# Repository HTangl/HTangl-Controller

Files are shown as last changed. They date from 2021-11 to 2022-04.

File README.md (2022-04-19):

# HTangl-Controller

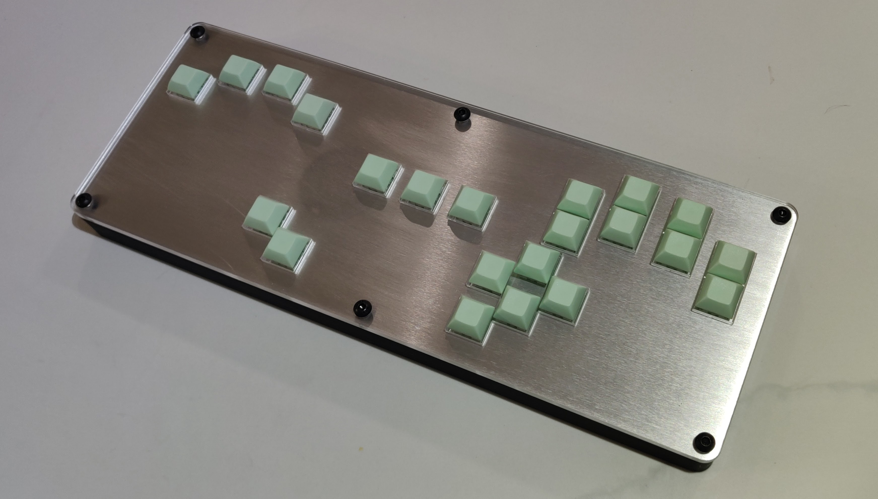
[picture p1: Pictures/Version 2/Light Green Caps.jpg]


The HTangl controller is an all digital game controller mainly made for Super Smash Brothers Melee  
but it can be used for many different games including traditional fighting games and platformers.  

It runs on a [modified version](https://github.com/HTangl/HTangl-Firmware) of the [HayB0XX firmware](https://github.com/JonnyHaystack/HayB0XX).  

The design of the controller is based on [The B0XX](https://b0xx.com/), [Frame 1](https://frame1.gg/) and [GCCMX](https://www.craneslab.xyz/projects/mx)  

This controller is not especially easy to DIY, Version 2 requiers a large 3D printed case which I print all in one piece on a large format FDM printer. The top panel and switch plate are also laser cut and the PCB requires some custom parts like the 2 USB ports. If you are not already somewhat familier with 3D printing, soldering, CAD and PCB manufacturing then I do not recommend trying to make one of these controllers.  

I created a simplified version of this controller specifically meant for DIY called the [BudgeTangl](https://github.com/HTangl/BudgeTangl), please check out that repository if you're just looking to make a simple controller.  

This controller is licensed under the CERN Open Hardware Licence Version 2 - Strongly Reciprocal. Please read the license in this repository and visit https://ohwr.org/cernohl for more information. This license allows you to make a modified or unmodified version of the controller for yourself or to sell provided you follow the guidelines of the license. The strongly reciprocal version of the license I have chosen requires that you use this same license if you decide to make modifications to any of the files in this repository.

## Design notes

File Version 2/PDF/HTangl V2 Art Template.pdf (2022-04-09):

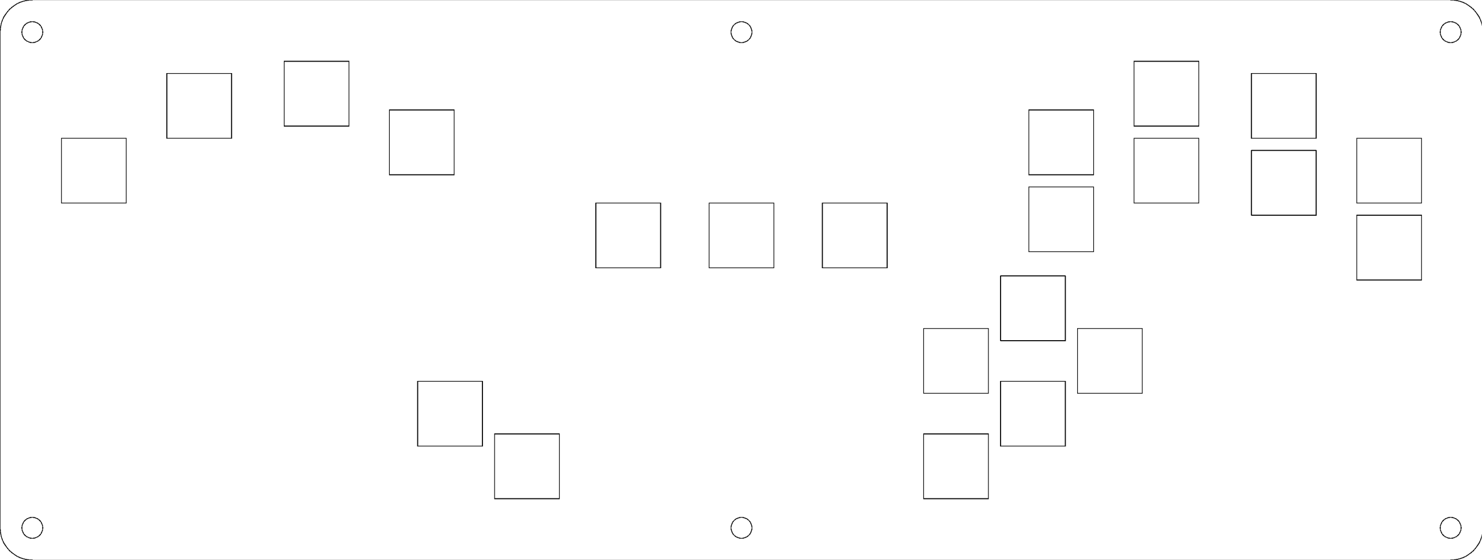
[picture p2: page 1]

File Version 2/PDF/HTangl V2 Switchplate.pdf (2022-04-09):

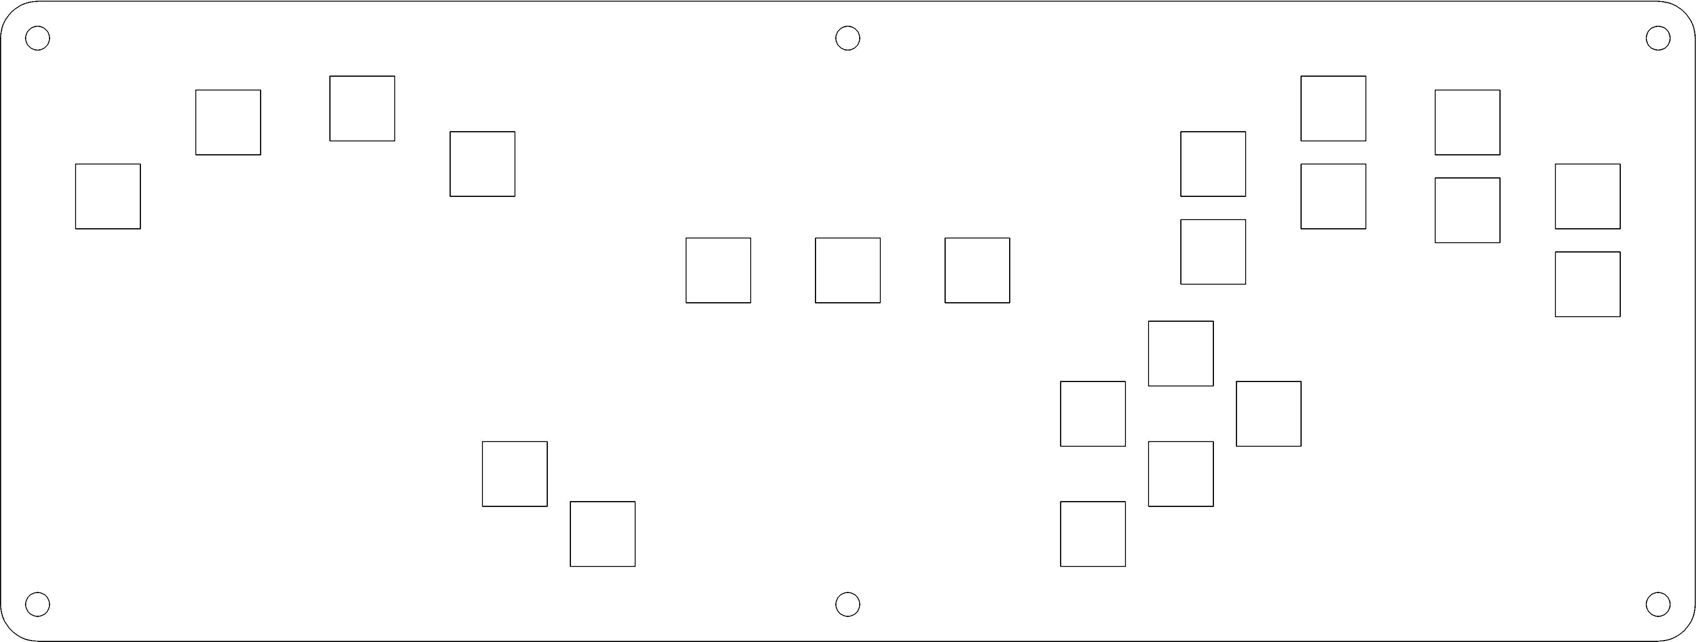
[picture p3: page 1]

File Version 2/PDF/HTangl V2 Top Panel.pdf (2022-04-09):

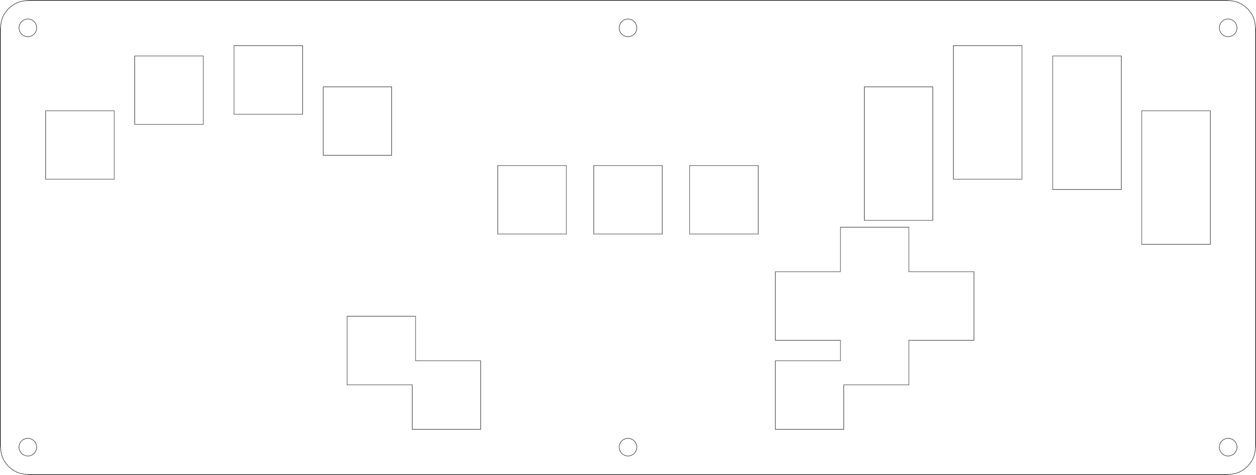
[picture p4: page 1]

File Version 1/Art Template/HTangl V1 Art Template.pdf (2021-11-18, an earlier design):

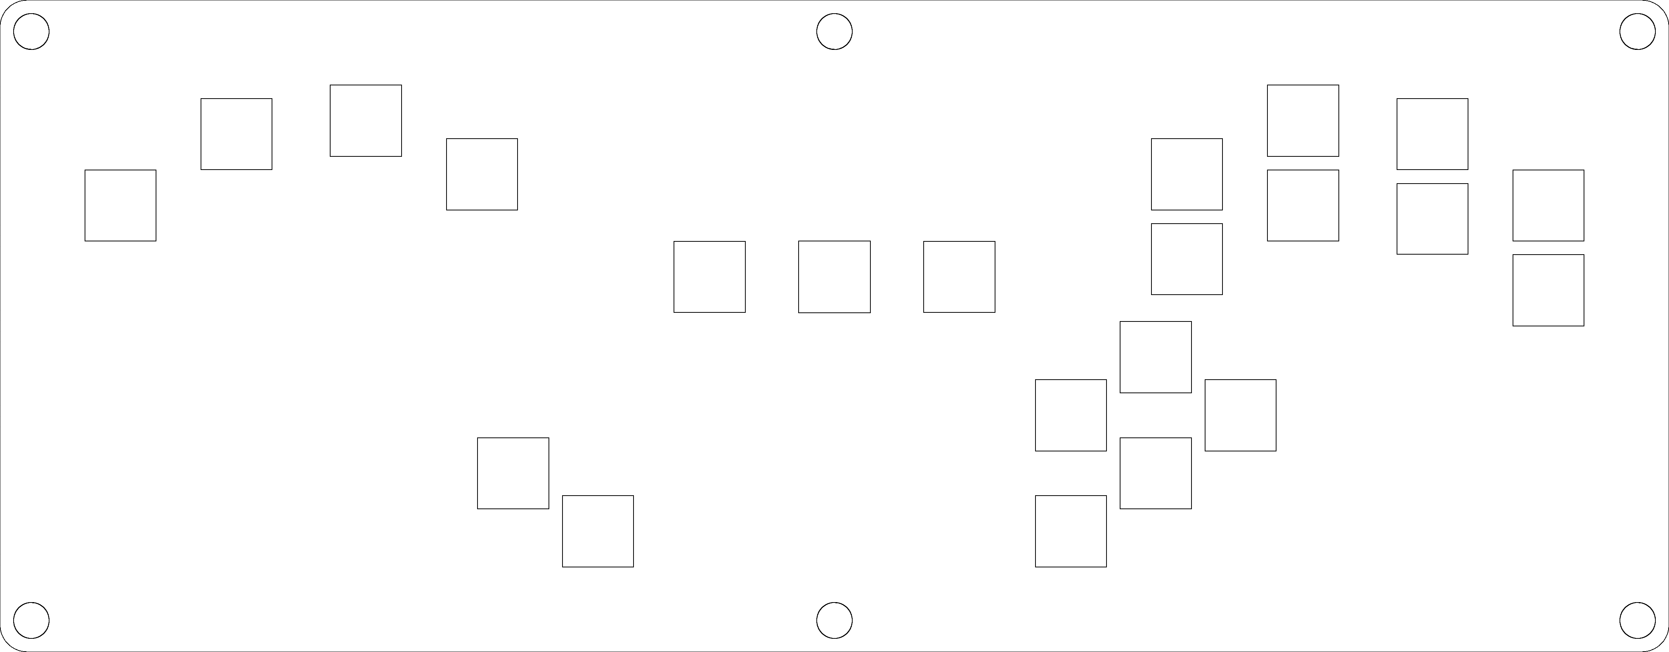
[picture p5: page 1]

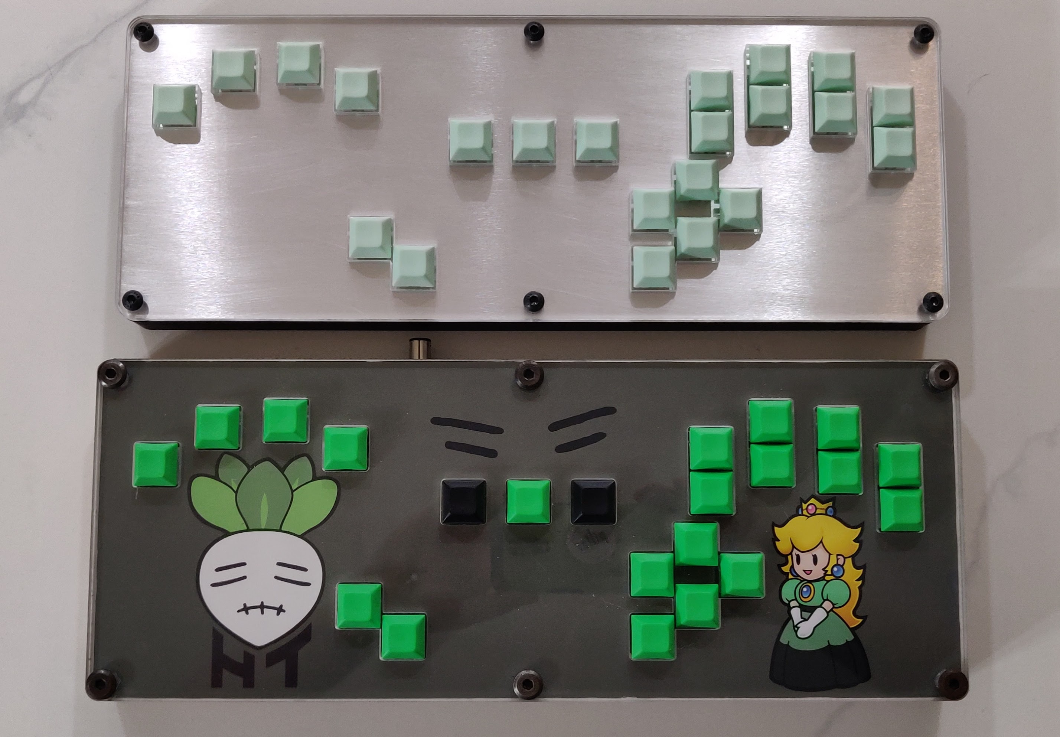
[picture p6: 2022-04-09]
Pictures/Version 2/V1 vs V2.jpg

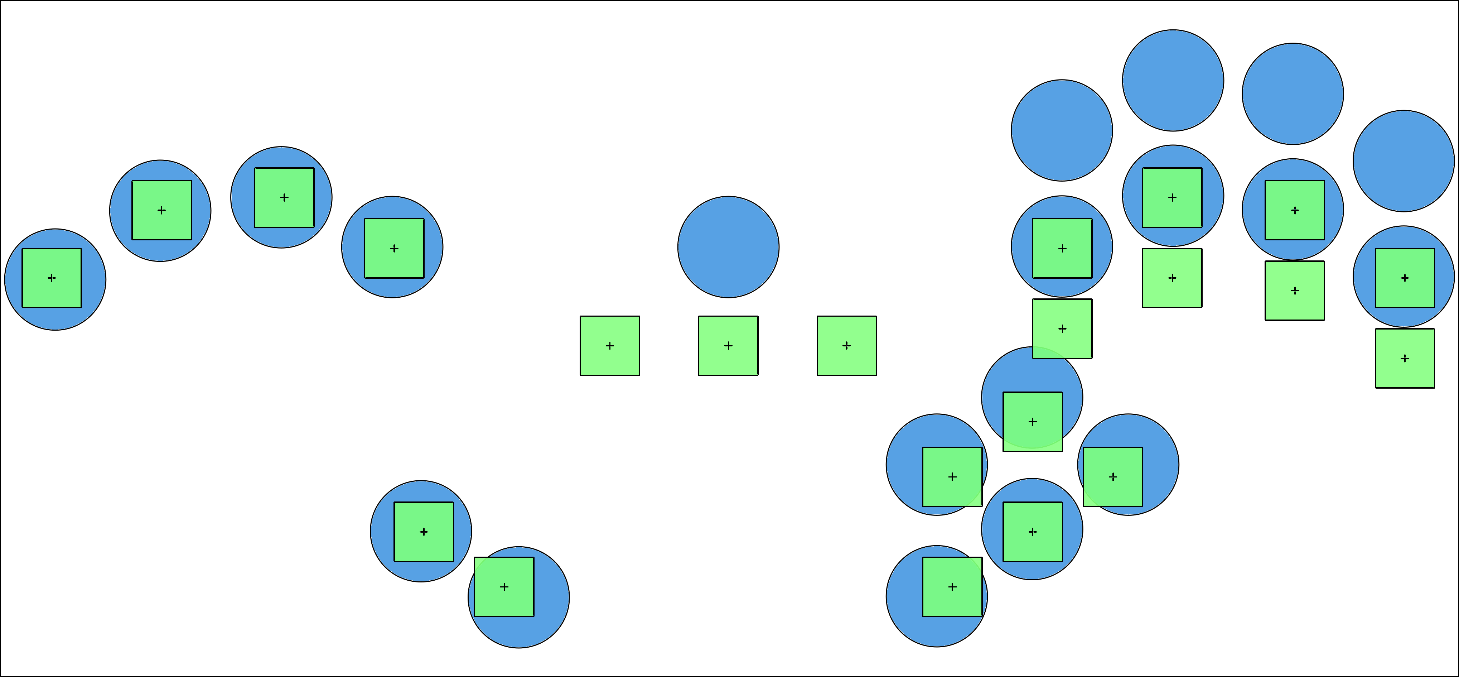
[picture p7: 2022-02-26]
Pictures/HTangl_B0XX_Comparison.png

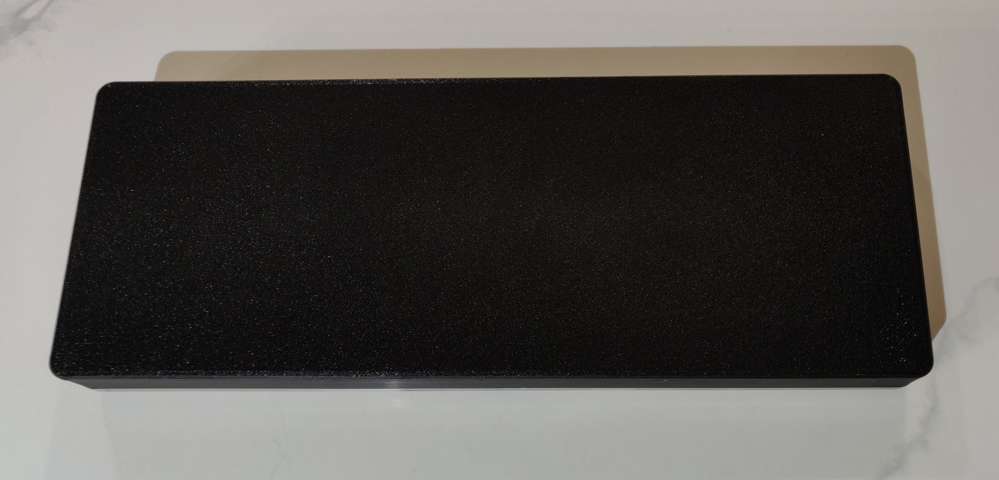
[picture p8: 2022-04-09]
Pictures/Version 2/Bottom.jpg

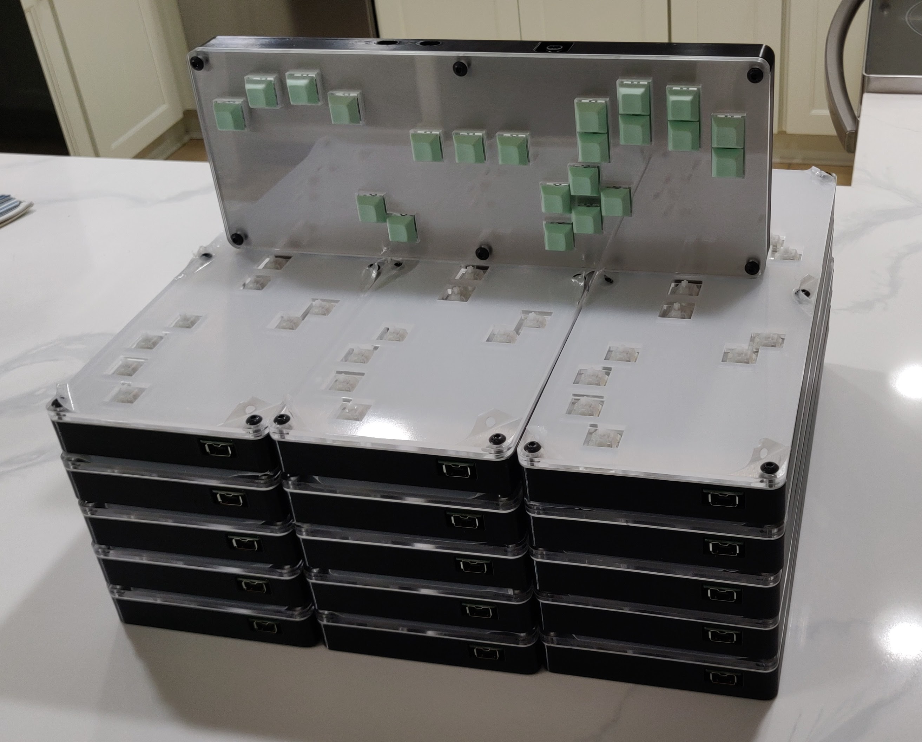
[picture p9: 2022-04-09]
Pictures/Version 2/Stack 1.jpg

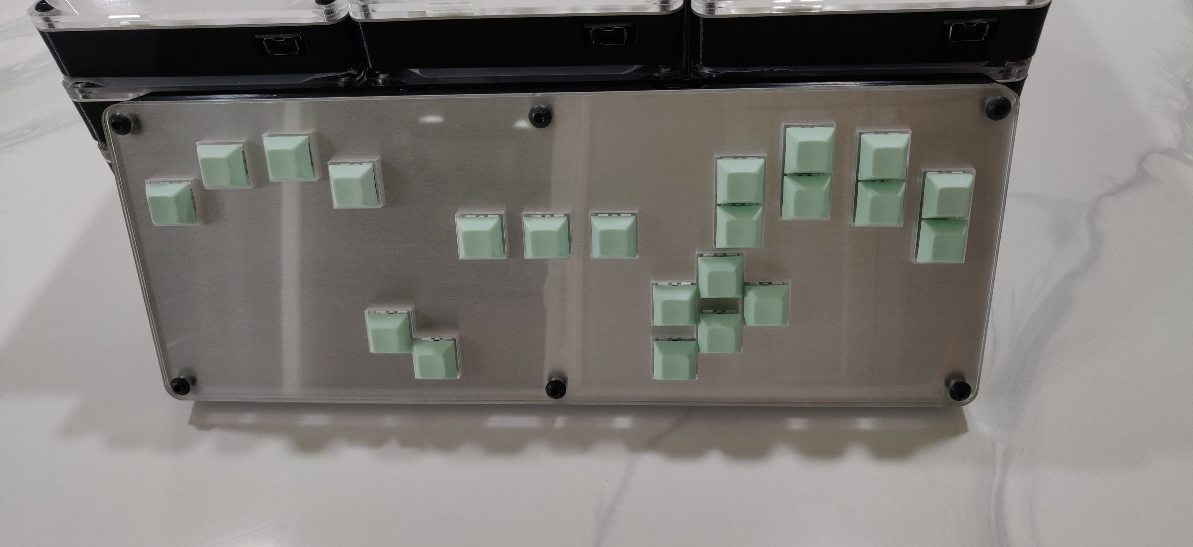
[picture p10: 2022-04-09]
Pictures/Version 2/Light Green Caps 2.jpg

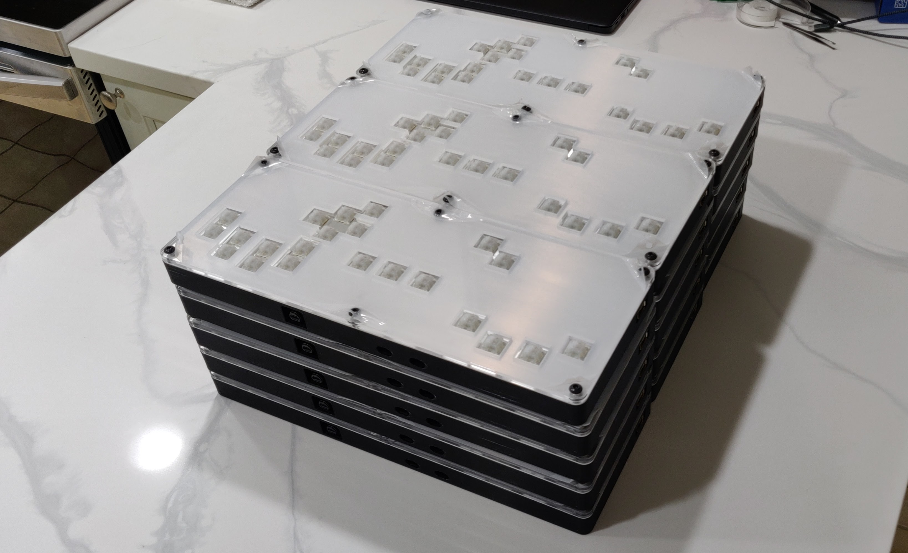
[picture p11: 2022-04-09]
Pictures/Version 2/Stack 2.jpg

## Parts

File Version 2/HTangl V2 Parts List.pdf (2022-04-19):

Part | Quantity | Link | Alternate Link
Main PCB | 1 | JLC
Model U USBC Breakout | 1 | JLC
Brook USBC Breakout | 1 | JLC
Male Micro USB Breakout | 1 | JLC
Logic Converter | 1 | https://amazon.com/dp/B07LG646VS
Adafruit ItsyBitsy | 1 | https://www.adafruit.com/product/3677
Nunchuk Port | 1 | https://www.aliexpress.com/item/32881749867.html
2 Position Screw Terminal | 2 | https://www.taydaelectronics.com/connectors-sockets/terminal-blocks/pcb-mount/dg128-screw-terminal-block-2-positions-2-54mm.html
4 Pin Female Header | 6 | https://www.taydaelectronics.com/4-pin-2-54-mm-single-row-female-pin-header.html
5 Pin Female Header | 1 | https://www.taydaelectronics.com/5-pin-2-54-mm-single-row-female-pin-header.html
6 Pin Female Header | 2 | https://www.taydaelectronics.com/6-pin-2-54mm-single-row-female-pin-header.html
15 Pin Female Header | 2 | https://www.taydaelectronics.com/15-pin-2-54-mm-single-row-female-pin-header.html
2x10 Pin Female Header | 1 | https://www.taydaelectronics.com/2x10-pin-2-54mm-double-row-female-pin-header.html
1N914 Diode | 2 | https://www.taydaelectronics.com/diodes/standard/1n914-small-signal-diode-200ma-100v.html
GC Port | 1 | https://www.aliexpress.com/item/4000512751256.html
Hot Swap Sockets | 22 | https://www.aliexpress.com/item/1005003166749340.html | https://mkultra.click/kailh-hotswap-sockets
Gateron Clear Switches | 22 | https://flashquark.com/product/pcb-mount-milky-gateron-switches-5-legs
DSA Keycaps | 22 | https://flashquark.com/product/solid-color-dsa-keycaps/ | https://www.aliexpress.com/item/32830177884.html
M5x16mm Screws | 6 | https://www.mcmaster.com/91239A232/
M3x5mm Screws | 4 | https://www.mcmaster.com/92005A114/
M5 Heat Inserts | 6 | https://www.mcmaster.com/97171A350/
M3 Heat Inserts | 4 | https://www.mcmaster.com/94180A331/

PETG Filament

about 1/3 of a
roll for 1
| controller | https://amazon.com/dp/B07PDV9RC8
Acrylic Top Panel | 2 | SendCutSend
Switch Plate | 1 | SendCutSend
GC Cable | 1 | https://amazon.com/dp/B07H54QQQH
M3 Hex Key | 1 | https://amazon.com/dp/B07VKJGGJB

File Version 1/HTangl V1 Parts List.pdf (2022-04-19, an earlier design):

Part | Quantitiy | Link
Gateron Clear 35 gram keyboard switches | 22
PBT DSA profile keycaps | 22
Kailh hotswap sockets | 22
Adafruit ItsyBitsy 32U4 - 5V Microcontroller | 1 | https://www.adafruit.com/product/3677
3.3v to 5v logic level converter | 1
USB micro to USB C panel mount cable | 1 | https://www.adafruit.com/product/4056
Switch plate to PCB screws - M3-0.5 x 12mm Flat Head | 9
Switch plate to PCB nuts - M3 nylon lock nut | 9
Panel mount USB C screws - M3-0.5 x 16mm Flat Head | 2
GC port screws - #4 x 1/2in pan head | 4
M6 x 25 Hex drive socket cap screws | 6 | https://amazon.com/gp/product/B08LQNHFVR
Gamecube controller extension cable | 2
5 pin 2.54 pitch screw terminal | 1

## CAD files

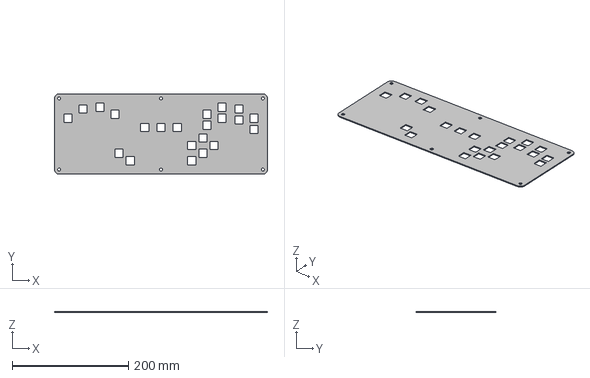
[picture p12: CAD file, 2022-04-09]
Version 2/STEP/HTangl V2 Switch Plate.step
366.4 x 138.4 x 1.60 mm

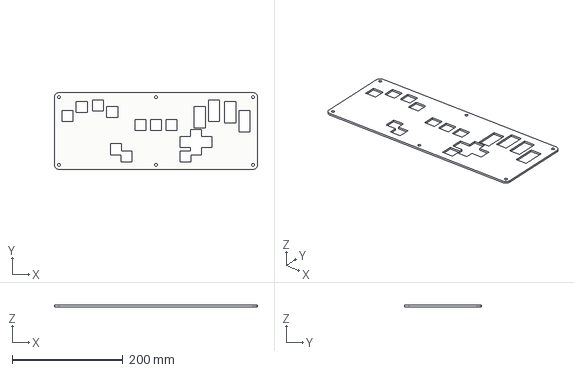
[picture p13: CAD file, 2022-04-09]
Version 2/STEP/HTangl V2 Top Panel.step
366.4 x 138.4 x 3.00 mm

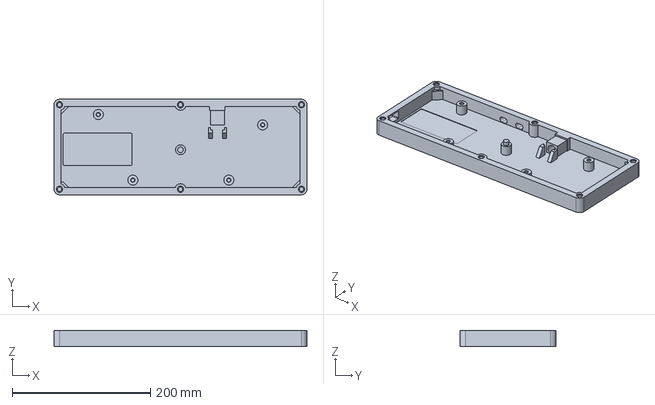
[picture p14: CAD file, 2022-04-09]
Version 2/STEP/HTangl V2 Case.step
366.4 x 138.4 x 23.4 mm

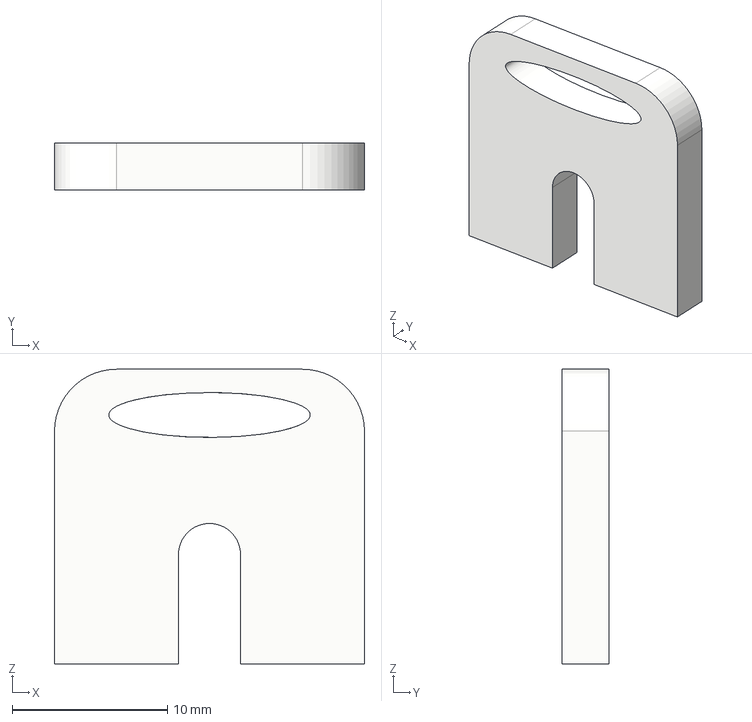
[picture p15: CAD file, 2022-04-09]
Version 2/STEP/GC Port Clip.step
20.0 x 3.00 x 19.0 mm

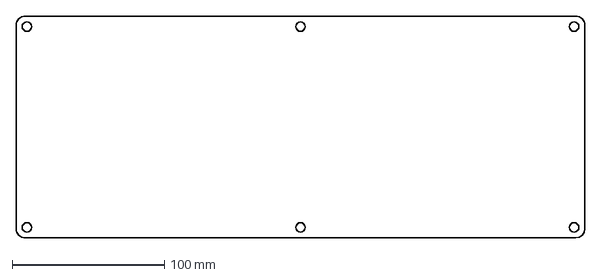
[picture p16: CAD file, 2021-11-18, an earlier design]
Version 1/DXF/HTangl V1.1 Bottom Panel.dxf
374.0 x 146.0 mm

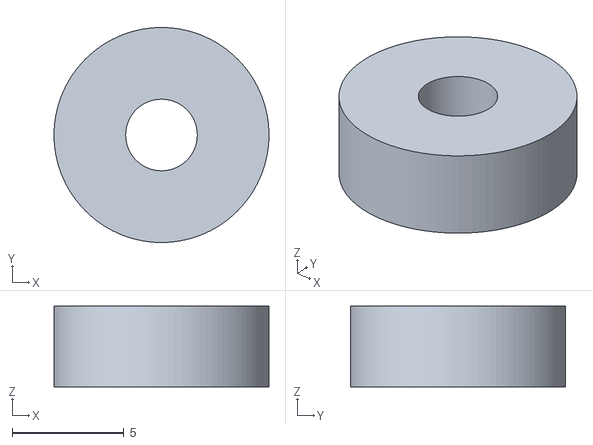
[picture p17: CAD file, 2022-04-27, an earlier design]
Version 1/STL/Switch Plate PCB Spacer.stl
9.60 x 9.60 x 3.60

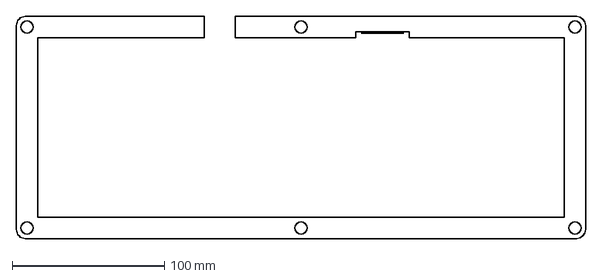
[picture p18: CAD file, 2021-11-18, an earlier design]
Version 1/DXF/HTangl V1.1 Frame.dxf
374.0 x 146.0 mm

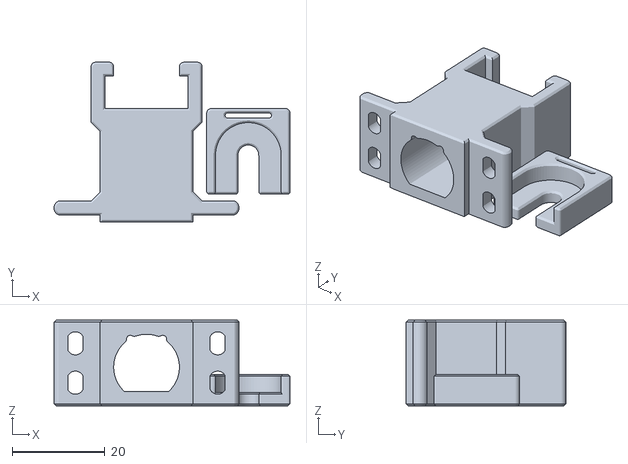
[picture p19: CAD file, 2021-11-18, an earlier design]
Version 1/STL/GC Bracket.stl
51.0 x 34.5 x 18.5

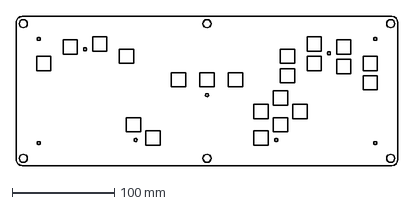
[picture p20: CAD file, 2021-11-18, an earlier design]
Version 1/DXF/HTangl V1.1 Switch Plate.dxf
374.0 x 146.0 mm

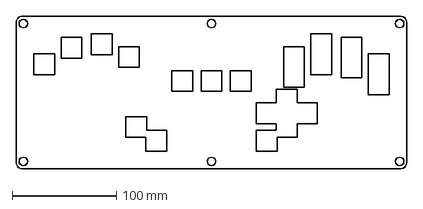
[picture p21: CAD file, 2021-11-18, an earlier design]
Version 1/DXF/HTangl V1.1 Top Panel.dxf
374.0 x 146.0 mm

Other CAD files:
Version 2/DXF/HTangl V2 Switch Plate.dxf
Version 2/DXF/HTangl V2 Top Panel.dxf
Version 2/Fusion 360/GC Port Clip.f3d
Version 2/Fusion 360/HTangl V2 Case.f3d
Version 2/Fusion 360/HTangl V2 Switch Plate.f3z
Version 2/Fusion 360/HTangl V2 Top Panel.f3d
Version 2/STL/GC Port Clip.stl
Version 2/STL/HTangl V2 Case.stl

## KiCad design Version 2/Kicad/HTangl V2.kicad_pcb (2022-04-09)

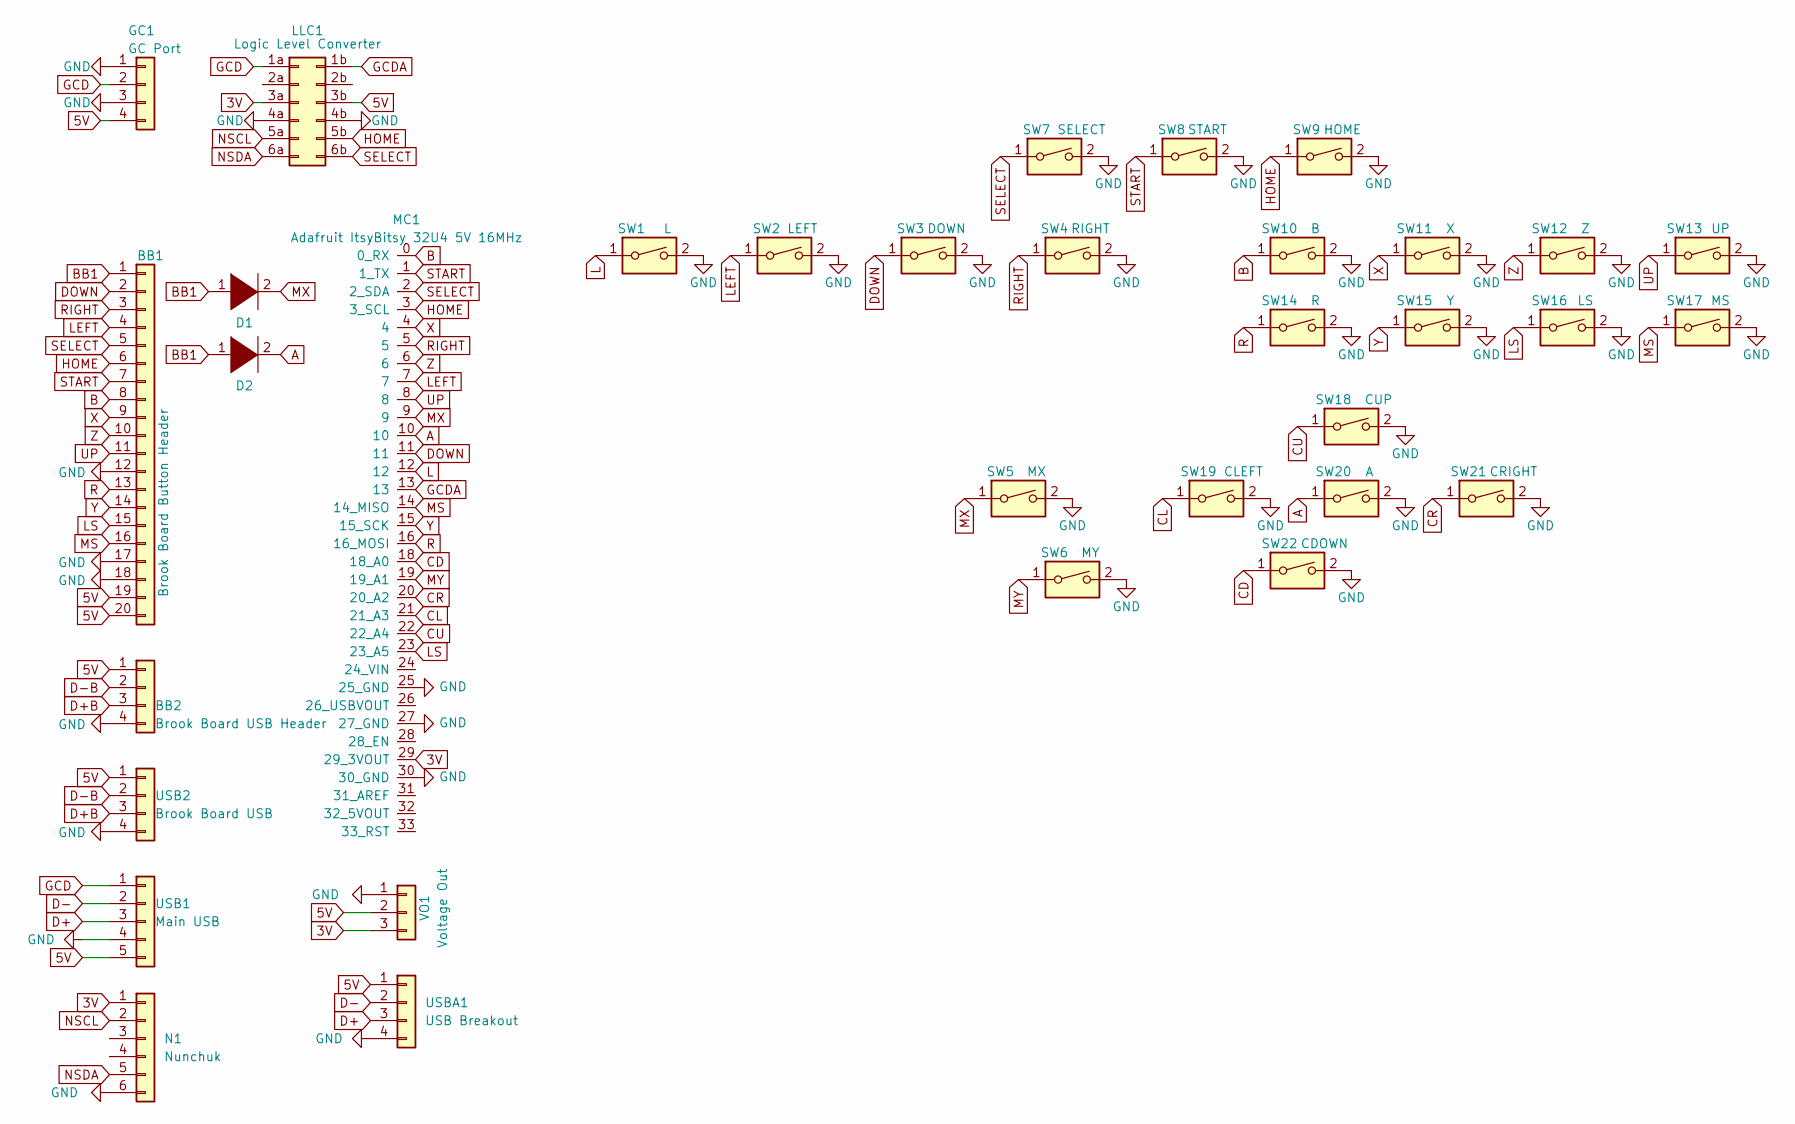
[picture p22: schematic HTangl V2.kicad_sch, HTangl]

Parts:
BB1: Brook Board Button Header; Brook_Board_Header_1
BB2: Brook Board USB Header; Brook_Board_Header_2
D1, D2: DIODE; D_DO-35_SOD27_P7.62mm_Horizontal
GC1: GC Port; PinSocket_1x04_P2.54mm_Vertical
LLC1: Logic Level Converter; LLC
MC1: Adafruit ItsyBitsy 32U4 5V 16MHz; Adafruit_32U4_5V
N1: Nunchuk; NunchuckFemale
SW1: L; Kailh_socket_MX_optional
SW2: LEFT; Kailh_socket_MX_optional
SW3: DOWN; Kailh_socket_MX_optional
SW4: RIGHT; Kailh_socket_MX_optional
SW5: MX; Kailh_socket_MX_optional
SW6: MY; Kailh_socket_MX_optional
SW7: SELECT; Kailh_socket_MX_optional
SW8: START; Kailh_socket_MX_optional
SW9: HOME; Kailh_socket_MX_optional
SW10: B; Kailh_socket_MX_optional
SW11: X; Kailh_socket_MX_optional
SW12: Z; Kailh_socket_MX_optional
SW13: UP; Kailh_socket_MX_optional
SW14: R; Kailh_socket_MX_optional
SW15: Y; Kailh_socket_MX_optional
SW16: LS; Kailh_socket_MX_optional
SW17: MS; Kailh_socket_MX_optional
SW18: CUP; Kailh_socket_MX_optional
SW19: CLEFT; Kailh_socket_MX_optional
SW20: A; Kailh_socket_MX_optional
SW21: CRIGHT; Kailh_socket_MX_optional
SW22: CDOWN; Kailh_socket_MX_optional
USB1: Main USB; Model_U_Header
USB2: Brook Board USB; Brook_Board_USBC
USBA1: USB Breakout; PinSocket_1x04_P2.54mm_Vertical
VO1: Voltage Out; PinHeader_1x03_P2.54mm_Vertical

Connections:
3V: LLC1.3a, MC1.29 (29_3VOUT), N1.1, VO1.3
5V: BB1.19, BB1.20, BB2.1, GC1.4, LLC1.3b, USB1.5, USB2.1, USBA1.1, VO1.2
A: D2.2 (A), MC1.10, SW20.1
B: BB1.8, MC1.0 (0_RX), SW10.1
BB1: BB1.1, D1.1 (K), D2.1 (K)
CD: MC1.18 (18_A0), SW22.1
CL: MC1.21 (21_A3), SW19.1
CR: MC1.20 (20_A2), SW21.1
CU: MC1.22 (22_A4), SW18.1
D+: USB1.3, USBA1.3
D+B: BB2.3, USB2.3
D-: USB1.2, USBA1.2
D-B: BB2.2, USB2.2
DOWN: BB1.2, MC1.11, SW3.1
GCD: GC1.2, LLC1.1a, USB1.1
GCDA: LLC1.1b, MC1.13
GND: BB1.12, BB1.17, BB1.18, BB2.4, GC1.1, GC1.3, LLC1.4a, LLC1.4b, MC1.25 (25_GND), MC1.27 (27_GND), MC1.30 (30_GND), N1.6, SW1.2, SW2.2, SW3.2, SW4.2, SW5.2, SW6.2, SW7.2, SW8.2, SW9.2, SW10.2, SW11.2, SW12.2, SW13.2, SW14.2, SW15.2, SW16.2, SW17.2, SW18.2, SW19.2, SW20.2, SW21.2, SW22.2, USB1.4, USB2.4, USBA1.4, VO1.1
HOME: BB1.6, LLC1.5b, MC1.3 (3_SCL), SW9.1
L: MC1.12, SW1.1
LEFT: BB1.4, MC1.7, SW2.1
LS: BB1.15, MC1.23 (23_A5), SW16.1
MS: BB1.16, MC1.14 (14_MISO), SW17.1
MX: D1.2 (A), MC1.9, SW5.1
MY: MC1.19 (19_A1), SW6.1
NSCL: LLC1.5a, N1.2
NSDA: LLC1.6a, N1.5
R: BB1.13, MC1.16 (16_MOSI), SW14.1
RIGHT: BB1.3, MC1.5, SW4.1
SELECT: BB1.5, LLC1.6b, MC1.2 (2_SDA), SW7.1
START: BB1.7, MC1.1 (1_TX), SW8.1
UP: BB1.11, MC1.8, SW13.1
X: BB1.9, MC1.4, SW11.1
Y: BB1.14, MC1.15 (15_SCK), SW15.1
Z: BB1.10, MC1.6, SW12.1

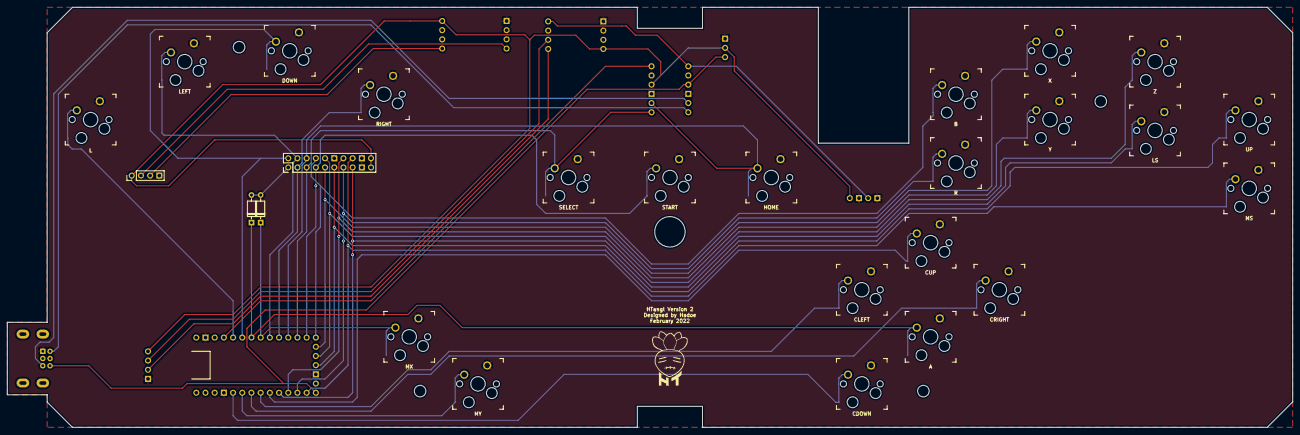
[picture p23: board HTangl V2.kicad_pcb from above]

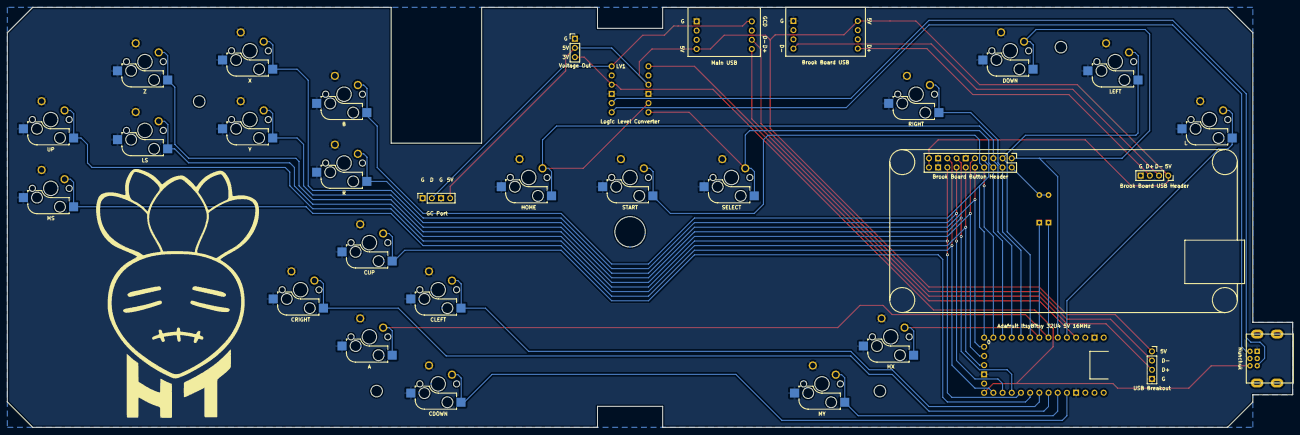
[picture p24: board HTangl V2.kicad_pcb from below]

Board: 2 copper layers, 355.0 x 116.0 mm, 38 parts (5 on the bottom side), 34 nets.

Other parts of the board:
., .#2, .#3, .#4: .; MountingHole_3.2mm_M3

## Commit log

2022-04-09 Added V2 files
    Added Version 2 files and re organized folders
    [GC Bracket V2 Multiple.stl, GC Bracket.stl, GC Port Clip.f3d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]
2022-04-09 Add V1 Parts List
    [HTangl V1 Parts List.xlsx]
2022-04-27 Update Switch Plate PCB Spacer.stl
    [Switch Plate PCB Spacer.stl]
